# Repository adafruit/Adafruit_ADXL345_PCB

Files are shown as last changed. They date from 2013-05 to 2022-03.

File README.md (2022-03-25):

# PCB for the Adafruit 5V ready ADXL345 Digital Triple-Axis Acceleromter (I2C or SPI)

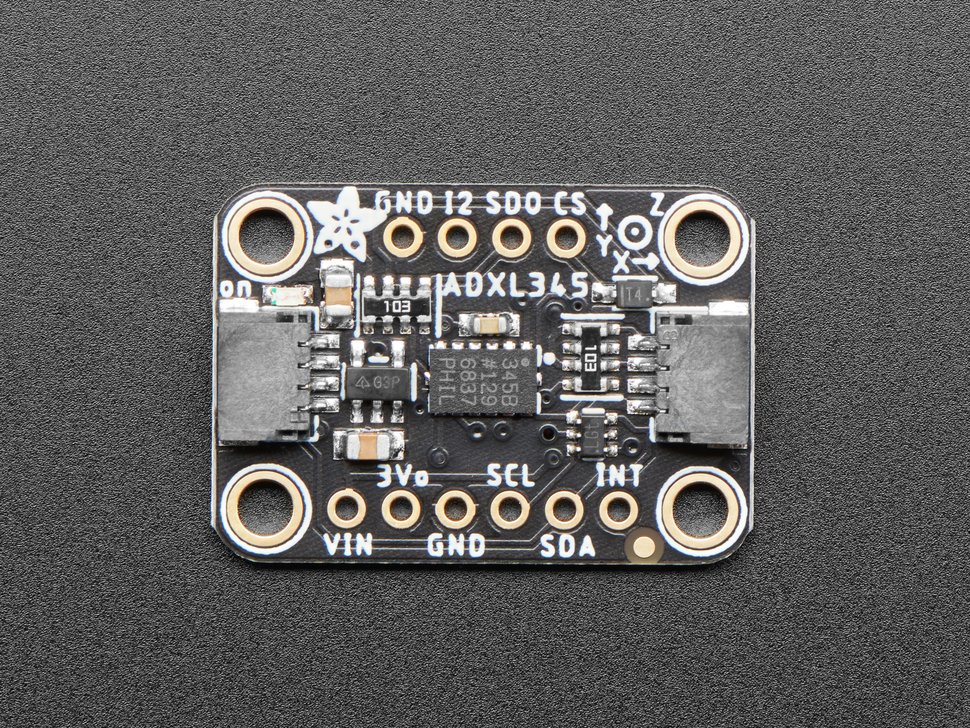
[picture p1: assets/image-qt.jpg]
<a href="http://www.adafruit.com/products/1231"><br/>
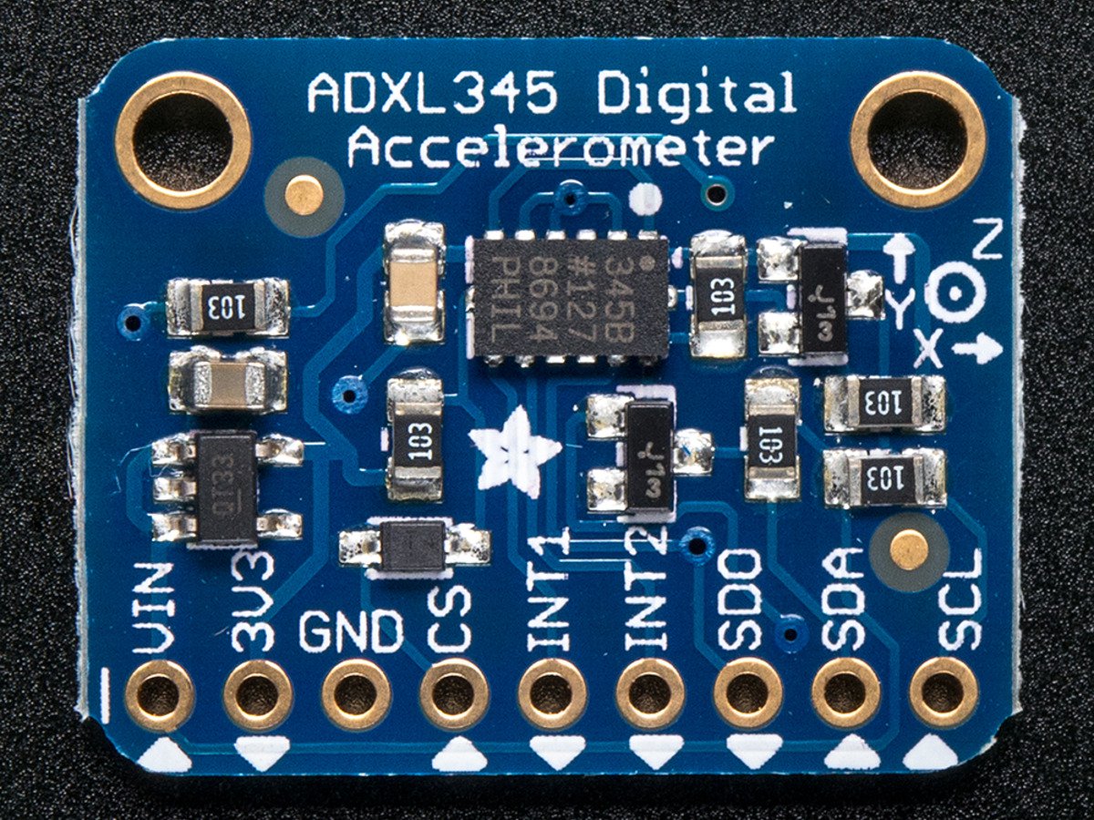
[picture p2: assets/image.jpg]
<a href="http://www.adafruit.com/products/1231"><br/>
Click here to purchase one from the Adafruit shop</a>

__Format is EagleCAD schematic and board layout__

Filling out our accelerometer offerings, we now have the really lovely digital ADXL345 from Analog Devices, a triple-axis accelerometer with digital I2C and SPI interface breakout. We added an on-board 3.3V regulator and logic-level shifting circuitry, making it a perfect choice for interfacing with any 3V or 5V microcontroller such as the Arduino.

The sensor has three axes of measurements, X Y Z, and pins that can be used either as I2C or SPI digital interfacing. You can set the sensitivity level to either +-2g, +-4g, +-8g or +-16g. The lower range gives more resolution for slow movements, the higher range is good for high speed tracking. The ADXL345 is the latest and greatest from Analog Devices, known for their exceptional quality MEMS devices. The VCC takes up to 5V in and regulates it to 3.3V with an output pin.

Fully assembled and tested. Comes with 9 pin 0.1" standard header in case you want to use it with a breadboard or perfboard. Two 2.5mm (0.1") mounting holes for easy attachment.

[Get started in a jiffy with our detailed tutorial!](https://learn.adafruit.com/adxl345-digital-accelerometer)

Adafruit invests time and resources providing this open source design, please support Adafruit and open-source hardware by purchasing products from Adafruit!

Designed by Adafruit Industries.
Creative Commons Attribution, Share-Alike license, check license.txt for more information.
All text above must be included in any redistribution.

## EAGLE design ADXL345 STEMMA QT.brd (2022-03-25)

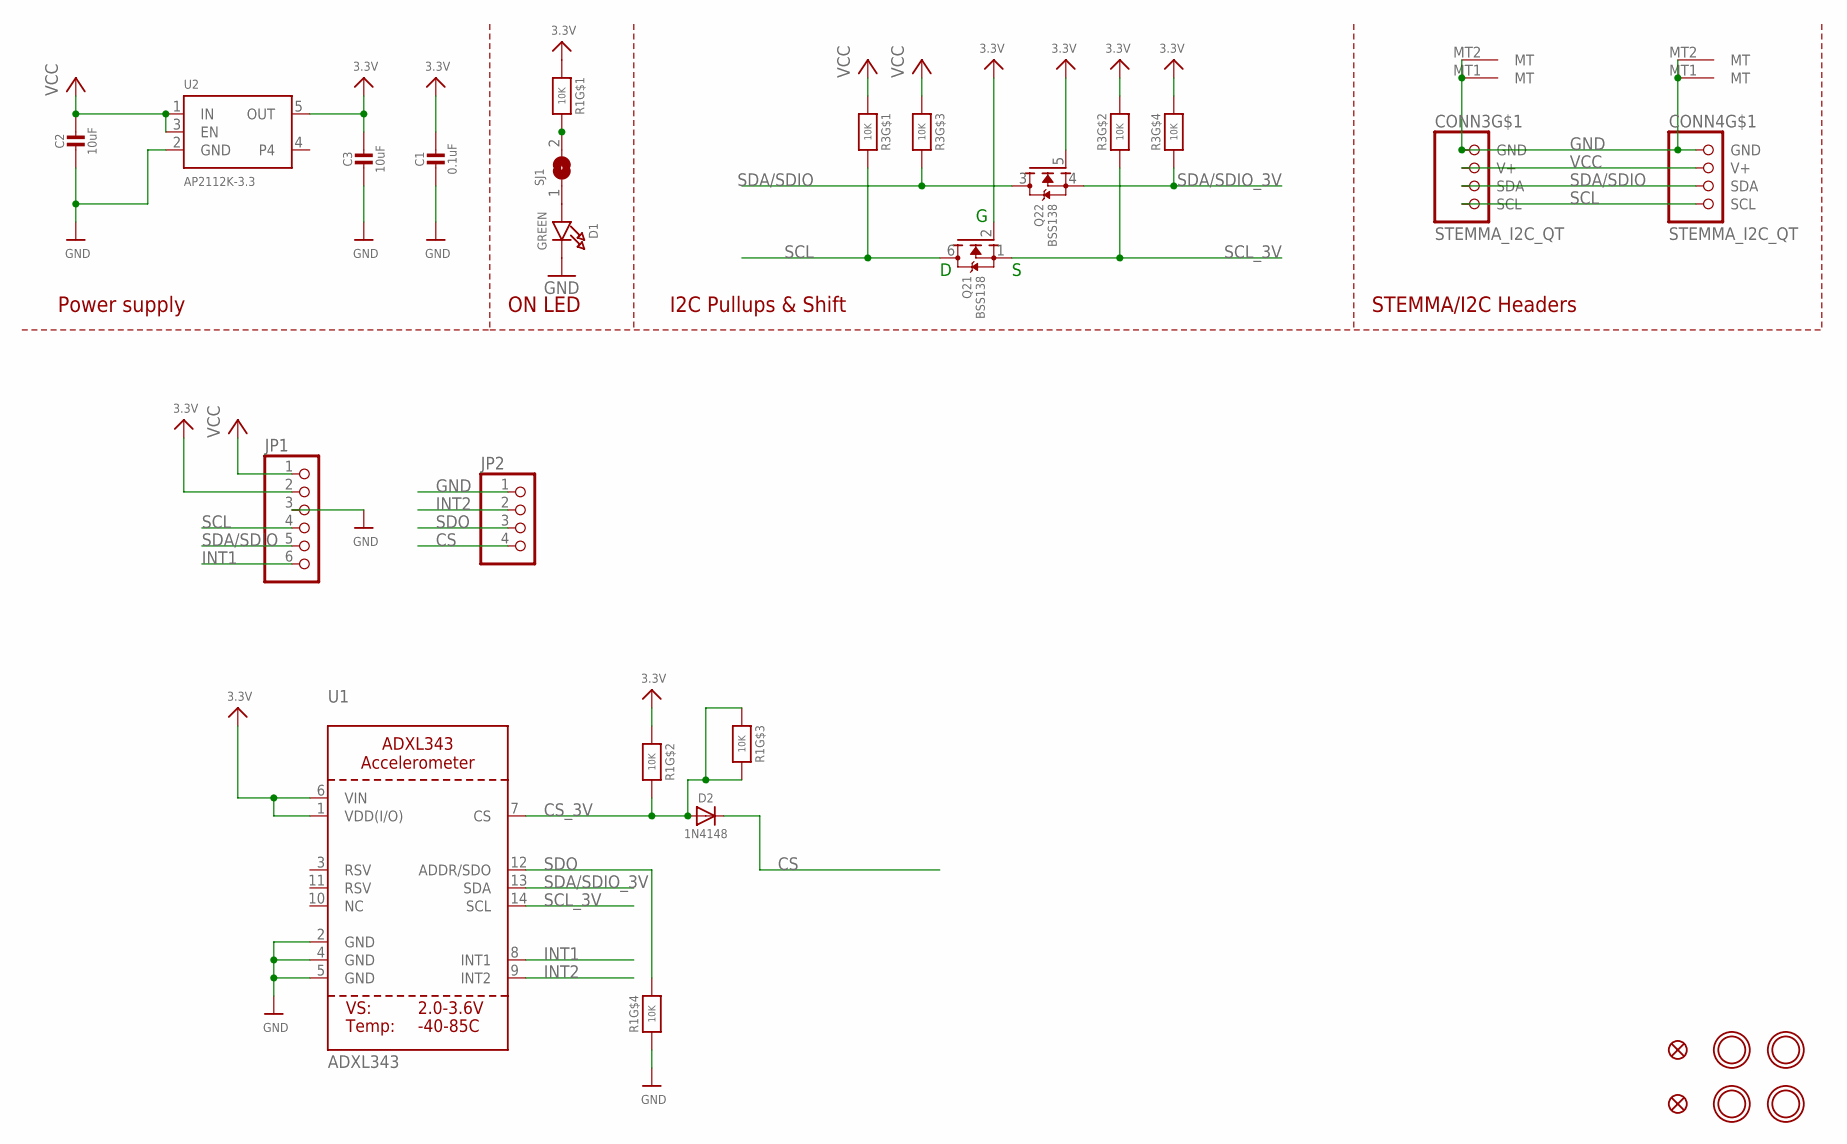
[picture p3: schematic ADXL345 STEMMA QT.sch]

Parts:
C1: 0.1uF; 0603-NO
C2: 10uF; _0805MP
C3: 10uF; 0805-NO
CONN3, CONN4: STEMMA_I2C_QT; JST_SH4
D1: GREEN; CHIPLED_0603_NOOUTLINE
D2: 1N4148; SOD-323
FID3, FID4: FIDUCIAL_1MM
JP1: HEADER-1X670MIL; 1X06_ROUND_70
JP2: HEADER-1X4ROUND; 1X04_ROUND
Q2: BSS138; SOT363
R1, R3: 10K; RESPACK_4X0603
SJ1: SOLDERJUMPERCLOSED; SOLDERJUMPER_CLOSEDWIRE
U1: ADXL343; LGA14
U2: AP2112K-3.3; SOT23-5
U$1, U$17, U$19, U$21: MOUNTINGHOLE2.5; MOUNTINGHOLE_2.5_PLATED

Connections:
3.3V: C1.1, C3.1, JP1.2, Q2.2 (G), Q2.5 (G), R1.1, R1.2 (1), R3.2 (1), R3.4 (1), U1.1 (VDD(I/O)), U1.6 (VIN), U2.5 (OUT)
CS: D2.C, JP2.4
CS_3V: D2.A, R1.3 (1), R1.6 (2), R1.7 (2), U1.7 (CS)
GND: C1.2, C2.2, C3.2, CONN3.1 (GND), CONN3.MT1 (MT), CONN3.MT2 (MT), CONN4.1 (GND), CONN4.MT1 (MT), CONN4.MT2 (MT), D1.C, JP1.3, JP2.1, R1.4 (1), U1.2 (GND), U1.4 (GND), U1.5 (GND), U2.2 (GND)
INT1: JP1.6, U1.8 (INT1)
INT2: JP2.2, U1.9 (INT2)
unnamed: R1.8 (2), SJ1.2
unnamed: D1.A, SJ1.1
SCL: CONN3.4 (SCL), CONN4.4 (SCL), JP1.4, Q2.6 (D), R3.8 (2)
SCL_3V: Q2.1 (S), R3.7 (2), U1.14 (SCL)
SDA/SDIO: CONN3.3 (SDA), CONN4.3 (SDA), JP1.5, Q2.3 (D), R3.6 (2)
SDA/SDIO_3V: Q2.4 (S), R3.5 (2), U1.13 (SDA)
SDO: JP2.3, R1.5 (2), U1.12 (ADDR/SDO)
VCC: C2.1, CONN3.2 (V+), CONN4.2 (V+), JP1.1, R3.1, R3.3 (1), U2.1 (IN), U2.3 (EN)

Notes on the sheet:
I2C Pullups & Shift
STEMMA/I2C Headers
ON LED
Power supply

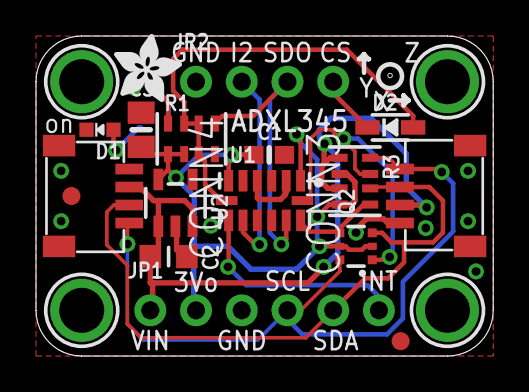
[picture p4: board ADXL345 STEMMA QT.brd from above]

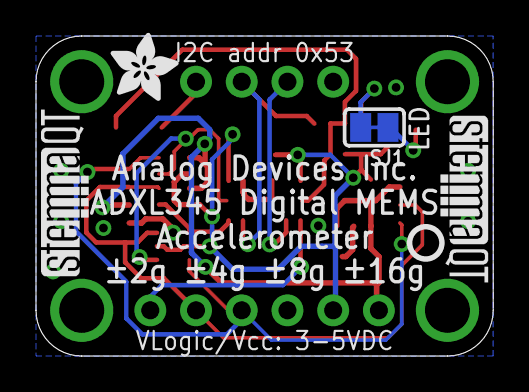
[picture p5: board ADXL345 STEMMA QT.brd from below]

Board: 2 copper layers, 25.4 x 17.8 mm, 26 parts (5 on the bottom side), 14 nets.

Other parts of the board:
U$4, U$11: ADAFRUIT_3.5MM
U$25: PCBFEAT-REV-040
U$30, U$31: STEMMAQT

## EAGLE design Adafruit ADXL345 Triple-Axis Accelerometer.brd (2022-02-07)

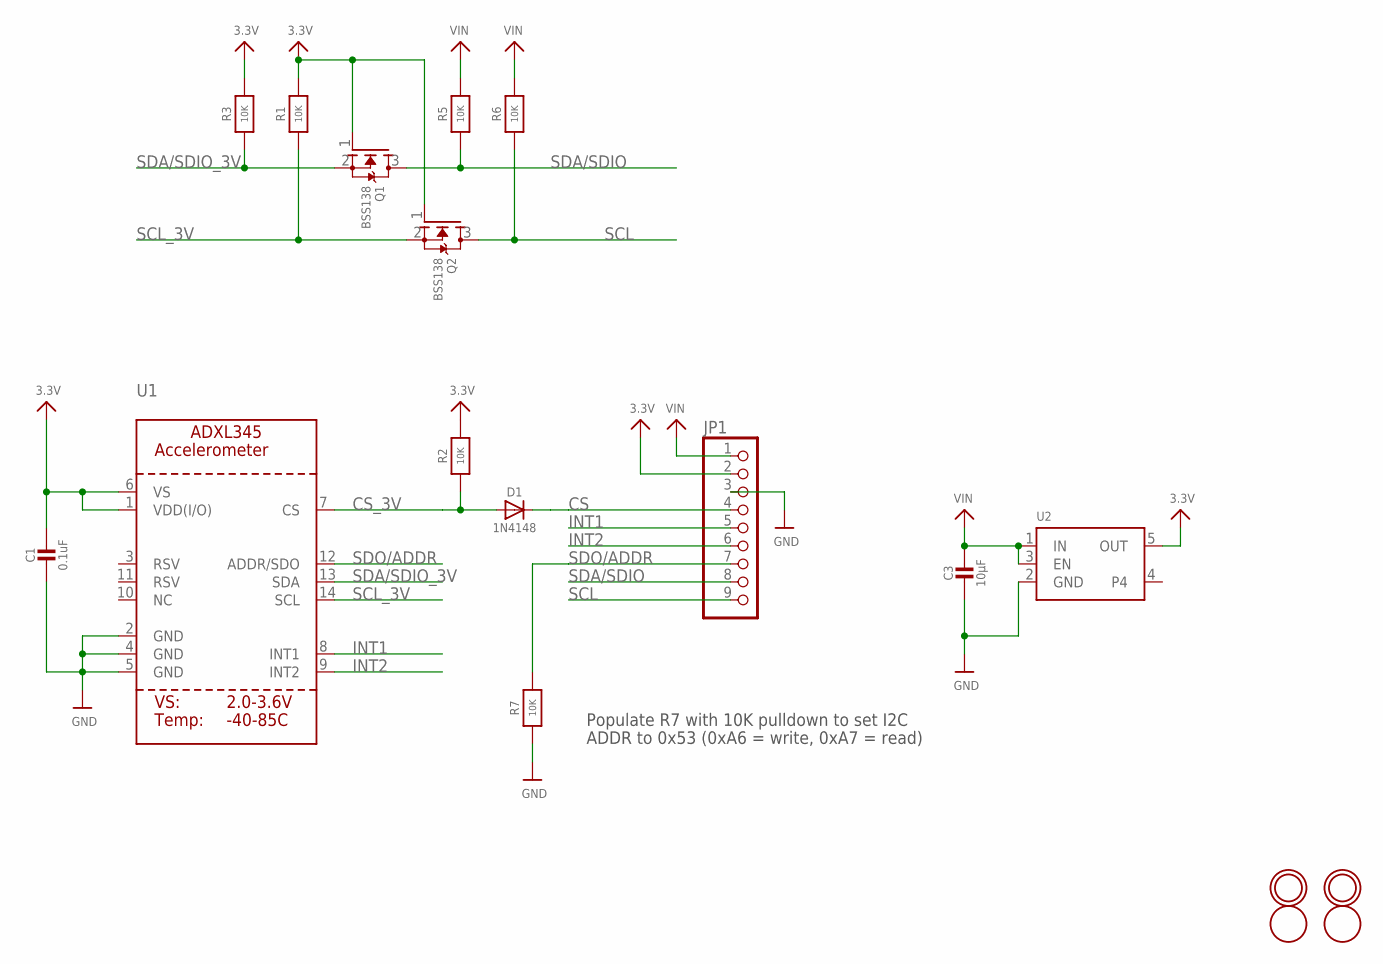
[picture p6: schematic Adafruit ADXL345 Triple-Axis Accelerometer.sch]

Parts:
C1: 0.1uF; 0805-NO
C3: 10µF; 0805-NO
D1: 1N4148; SOD-323_MINI
JP1: HEADER-1X970MIL; 1X09_ROUND_70
Q1, Q2: BSS138; SOT23-WIDE
R1, R2, R3, R5, R6, R7: 10K; 0805-NO
U1: ACCEL_ADXL345; LGA14
U2: VREG_SOT23-5; SOT23-5
U$1, U$3: FIDUCIAL; FIDUCIAL_1MM
U$4, U$6: MOUNTINGHOLE2.5; MOUNTINGHOLE_2.5_PLATED

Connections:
3.3V: C1.1, JP1.2, Q1.1 (G), Q2.1 (G), R1.2, R2.2, R3.2, U1.1 (VDD(I/O)), U1.6 (VS), U2.5 (OUT)
CS: D1.C, JP1.4
CS_3V: D1.A, R2.1, U1.7 (CS)
GND: C1.2, C3.2, JP1.3, R7.1, U1.2 (GND), U1.4 (GND), U1.5 (GND), U2.2 (GND)
INT1: JP1.5, U1.8 (INT1)
INT2: JP1.6, U1.9 (INT2)
SCL: JP1.9, Q2.3 (D), R6.1
SCL_3V: Q2.2 (S), R1.1, U1.14 (SCL)
SDA/SDIO: JP1.8, Q1.3 (D), R5.1
SDA/SDIO_3V: Q1.2 (S), R3.1, U1.13 (SDA)
SDO/ADDR: JP1.7, R7.2, U1.12 (ADDR/SDO)
VIN: C3.1, JP1.1, R5.2, R6.2, U2.1 (IN), U2.3 (EN)

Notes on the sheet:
Populate R7 with 10K pulldown to set I2C
ADDR to 0x53 (0xA6 = write, 0xA7 = read)

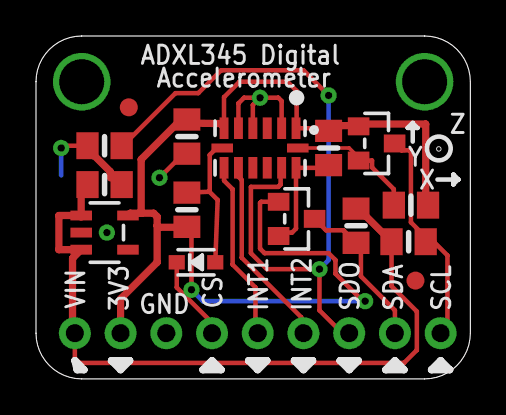
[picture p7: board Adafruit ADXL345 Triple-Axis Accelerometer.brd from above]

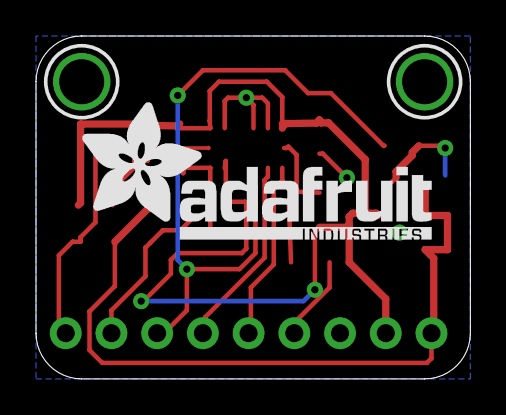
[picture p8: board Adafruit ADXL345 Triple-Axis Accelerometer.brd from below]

Board: 2 copper layers, 24.1 x 19.1 mm, 19 parts (3 on the bottom side), 12 nets.

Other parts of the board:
U$7: ADAFRUIT_TEXT_20MM

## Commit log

2022-02-07 Add current board files.
    [Adafruit ADXL345 Triple-Axis Accelerometer.brd, Adafruit ADXL345 Triple-Axis Accelerometer.sch]
2022-03-25 Updating for STEMMA QT version
    [ADXL345 STEMMA QT.brd, ADXL345 STEMMA QT.sch]

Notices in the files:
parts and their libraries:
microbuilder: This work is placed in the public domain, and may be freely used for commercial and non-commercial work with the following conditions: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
